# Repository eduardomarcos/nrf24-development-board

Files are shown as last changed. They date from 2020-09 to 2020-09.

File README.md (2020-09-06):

# NRF24 Development Board

The goal of this repository is to keep a version of a useful development boards for my [MySensors](https://www.mysensors.org/) projects based on atmega 328, esp32 and nrf24l01 module, so I do not need to wire all componentes into a breadboard.

## Atmega328 Development Board

Features:
* Almost all I/O pins available for direct connection
* Uses [3.3V Boost Buck](https://es.aliexpress.com/item/32822323191.html) for an input up to 5V (Considering that the sensor will be powered by a [TP4056](https://www.best-microcontroller-projects.com/tp4056.html) battery charger)
* If voltage regulator is wired by a connector headers instead of soldering, it would be possible to use a different voltage regulator (keep in mind that nrf24 module works with no more than ~3.6V or could be damaged)
* Internal voltage of 3.3 for the atmega 328
* NRF24L01 wired with a 10uF capacitor for noise reduction
* Reset button
* On board jumpers to disable 16 MHz crystal (and use internal 8 MHz from atmega 328)

This is the way it looks like:

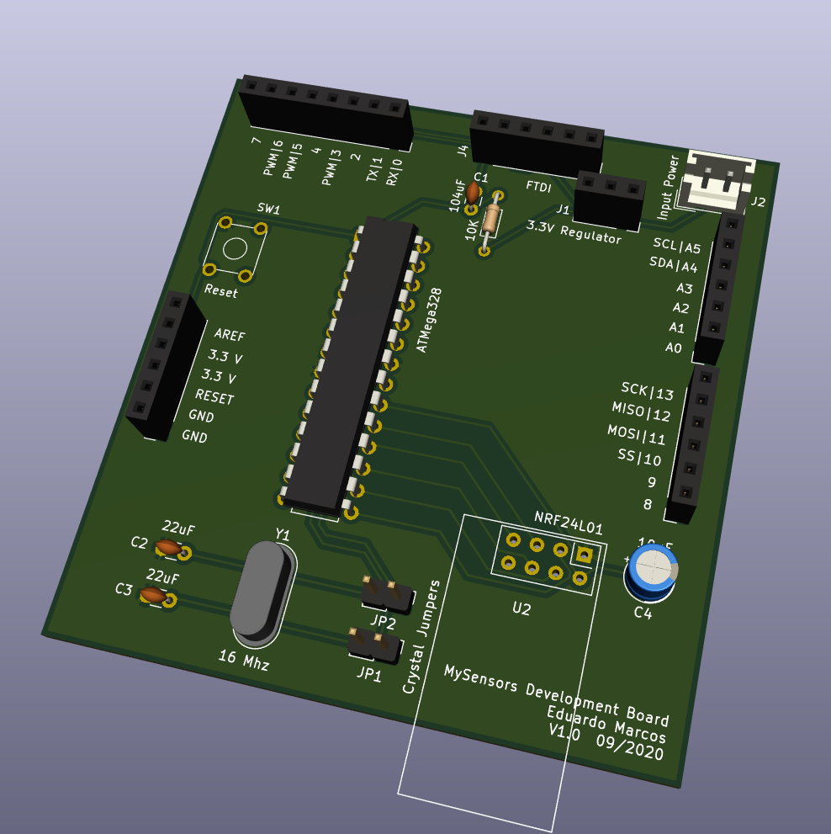
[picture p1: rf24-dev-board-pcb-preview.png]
Pcb board preview


## Esp32 Development Board

Features:
* All I/O pins available for direct connection
* NRF24L01 wired with an optional capacitor for noise reduction
* Err Tx and Rx led diodes for mysensors capability

This is the way it looks like:

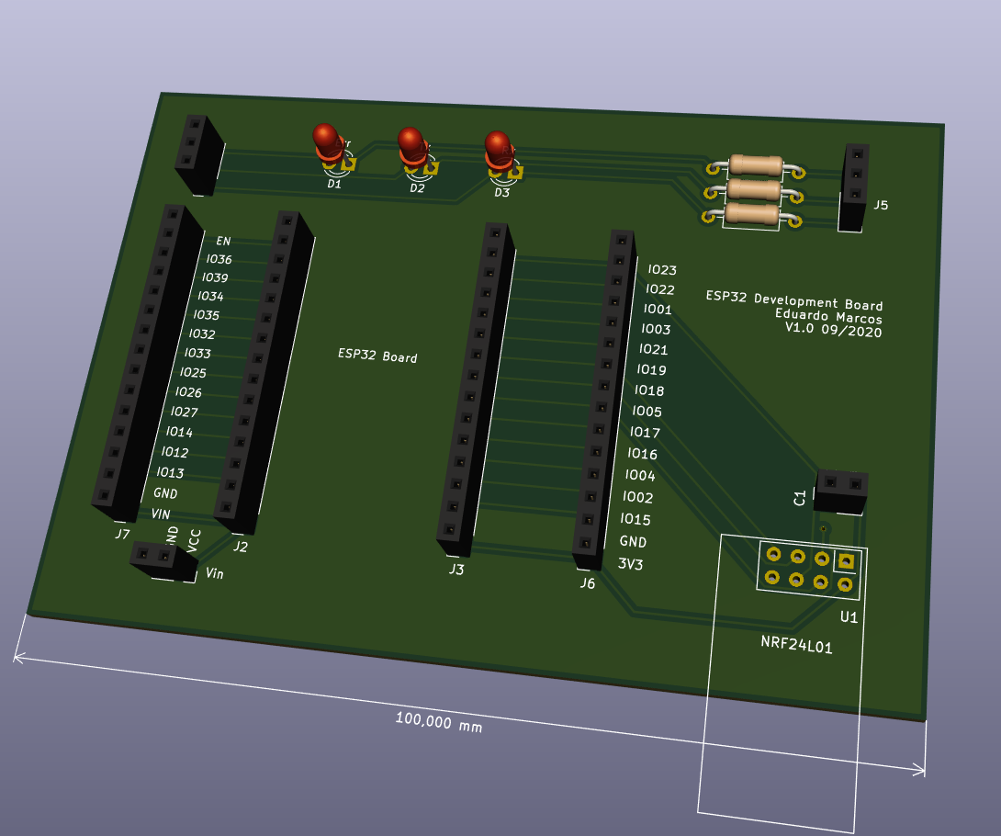
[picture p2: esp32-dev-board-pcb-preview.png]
Pcb board preview


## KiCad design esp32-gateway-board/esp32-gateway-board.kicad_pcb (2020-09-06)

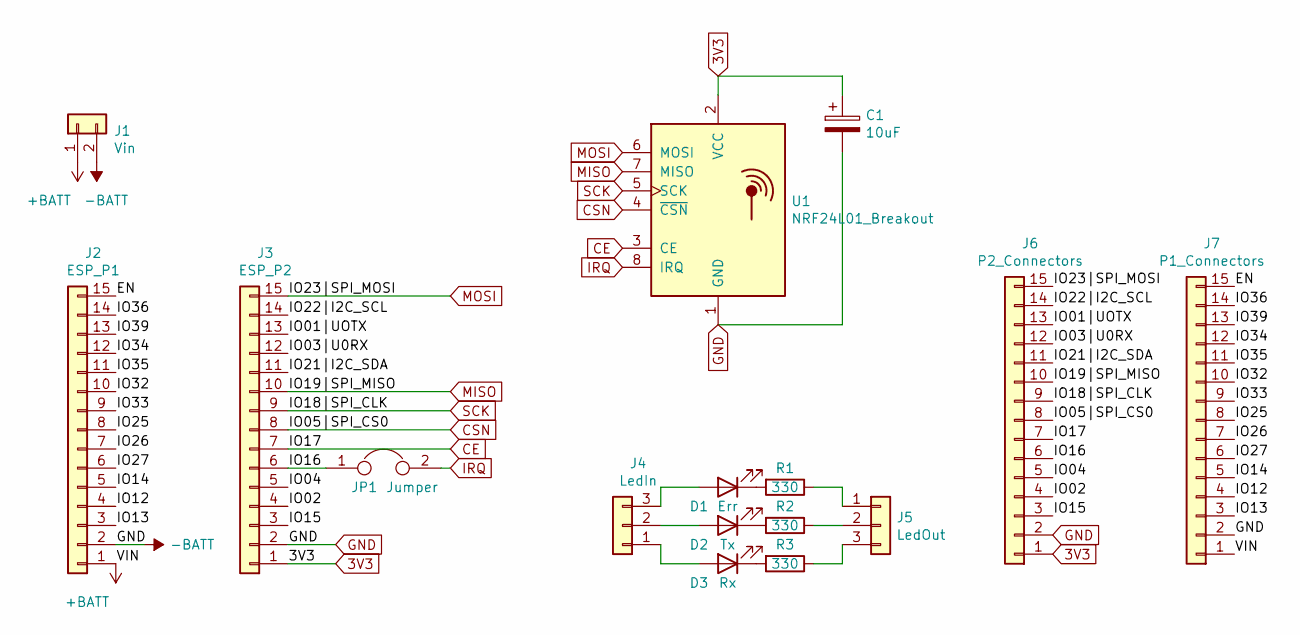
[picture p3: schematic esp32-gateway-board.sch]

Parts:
C1: 10uF; PinSocket_1x02_P2.54mm_Vertical
D1: Err; LED_D3.0mm
D2: Tx; LED_D3.0mm
D3: Rx; LED_D3.0mm
J1: Vin; PinSocket_1x02_P2.54mm_Vertical
J2: ESP_P1; PinSocket_1x15_P2.54mm_Vertical
J3: ESP_P2; PinSocket_1x15_P2.54mm_Vertical
J4: LedIn; PinSocket_1x03_P2.54mm_Vertical
J5: LedOut; PinSocket_1x03_P2.54mm_Vertical
J6: P2_Connectors; PinSocket_1x15_P2.54mm_Vertical
J7: P1_Connectors; PinSocket_1x15_P2.54mm_Vertical
JP1: Jumper; PinHeader_1x02_P2.54mm_Vertical
R1, R2, R3: 330; R_Axial_DIN0207_L6.3mm_D2.5mm_P10.16mm_Horizontal
U1: NRF24L01_Breakout; nRF24L01_Breakout

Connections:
3V3: C1.1, J3.1, J6.1, U1.2 (VCC)
+BATT: J1.1, J2.1, J7.1
/EN: J2.15, J7.15
/IO01|UOTX: J3.13, J6.13
/IO02: J3.4, J6.4
/IO03|U0RX: J3.12, J6.12
/IO04: J3.5, J6.5
/IO12: J2.4, J7.4
/IO13: J2.3, J7.3
/IO14: J2.5, J7.5
/IO15: J3.3, J6.3
/IO16: J3.6, J6.6, JP1.1
/IO21|I2C_SDA: J3.11, J6.11
/IO22|I2C_SCL: J3.14, J6.14
/IO25: J2.8, J7.8
/IO26: J2.7, J7.7
/IO27: J2.6, J7.6
/IO32: J2.10, J7.10
/IO33: J2.9, J7.9
/IO34: J2.12, J7.12
/IO35: J2.11, J7.11
/IO36: J2.14, J7.14
/IO39: J2.13, J7.13
CE: J3.7, J6.7, U1.3 (CE)
CSN: J3.8, J6.8, U1.4 (~CSN)
GND: C1.2, J1.2, J2.2, J3.2, J6.2, J7.2, U1.1 (GND)
MISO: J3.10, J6.10, U1.7 (MISO)
MOSI: J3.15, J6.15, U1.6 (MOSI)
unnamed: D1.1 (K), R1.2
unnamed: D1.2 (A), J4.3
unnamed: D2.1 (K), R2.2
unnamed: D2.2 (A), J4.2
unnamed: D3.1 (K), R3.2
unnamed: D3.2 (A), J4.1
unnamed: J5.1, R1.1
unnamed: J5.2, R2.1
unnamed: J5.3, R3.1
unnamed: JP1.2, U1.8 (IRQ)
SCK: J3.9, J6.9, U1.5 (SCK)

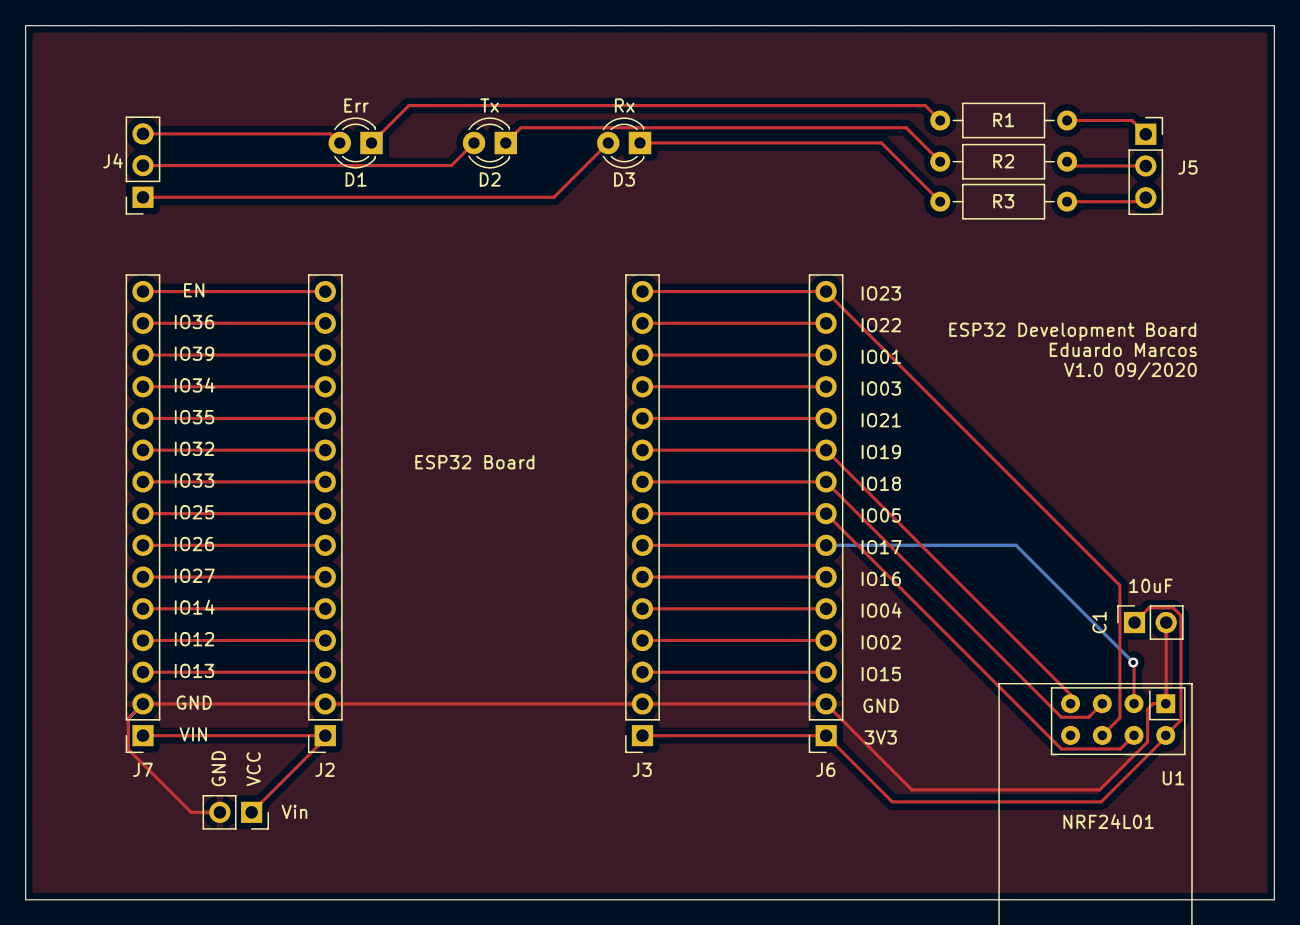
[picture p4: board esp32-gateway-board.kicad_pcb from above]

Board: 2 copper layers, 100.0 x 70.0 mm, 15 parts (0 on the bottom side), 38 nets.

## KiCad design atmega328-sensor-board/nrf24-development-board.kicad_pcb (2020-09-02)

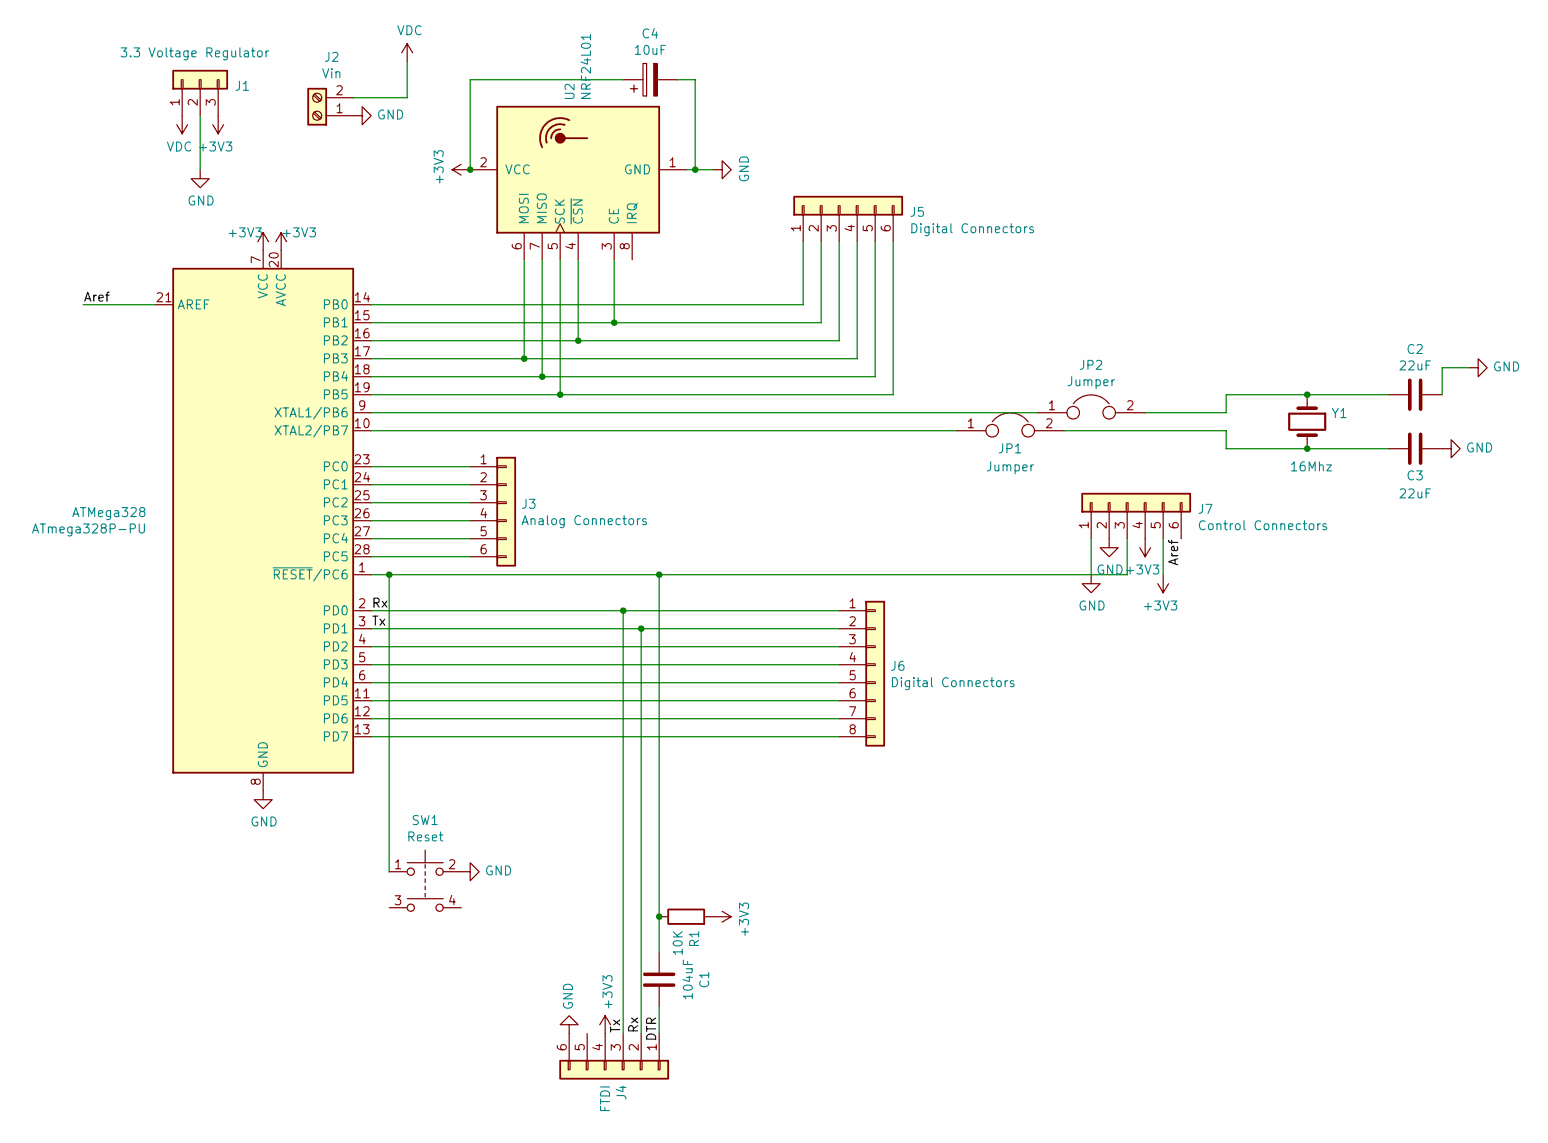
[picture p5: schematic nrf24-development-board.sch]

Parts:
ATMega328: ATmega328P-PU; DIP-28_W7.62mm
C1: 104uF; C_Disc_D3.0mm_W1.6mm_P2.50mm
C2, C3: 22uF; C_Disc_D3.0mm_W1.6mm_P2.50mm
C4: 10uF; CP_Radial_D5.0mm_P2.50mm
J1: 3.3 Voltage Regulator; PinSocket_1x03_P2.54mm_Vertical
J2: Vin; JST_EH_B2B-EH-A_1x02_P2.50mm_Vertical
J3: Analog Connectors; PinSocket_1x06_P2.54mm_Vertical
J4: FTDI; PinSocket_1x06_P2.54mm_Vertical
J5: Digital Connectors; PinSocket_1x06_P2.54mm_Vertical
J6: Digital Connectors; PinSocket_1x08_P2.54mm_Vertical
J7: Control Connectors; PinSocket_1x06_P2.54mm_Vertical
JP1, JP2: Jumper; PinHeader_1x02_P2.54mm_Vertical
R1: 10K; R_Axial_DIN0204_L3.6mm_D1.6mm_P7.62mm_Horizontal
SW1: Reset; SW_TH_Tactile_Omron_B3F-10xx
U2: NRF24L01; nRF24L01_Breakout
Y1: 16Mhz; Crystal_HC49-4H_Vertical

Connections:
+3V3: ATMega328.7 (VCC), ATMega328.20 (AVCC), C4.1, J1.3, J4.4, J7.4, J7.5, R1.2, U2.2 (VCC)
/Aref: ATMega328.21 (AREF), J7.6
/DTR: C1.1, J4.1
/Rx: ATMega328.2 (PD0), ATMega328.3 (PD1), J4.2, J4.3, J6.1, J6.2
unnamed: ATMega328.4 (PD2), J6.3
unnamed: ATMega328.5 (PD3), J6.4
unnamed: ATMega328.6 (PD4), J6.5
unnamed: ATMega328.9 (XTAL1/PB6), JP2.1
unnamed: ATMega328.10 (XTAL2/PB7), JP1.1
unnamed: ATMega328.11 (PD5), J6.6
unnamed: ATMega328.12 (PD6), J6.7
unnamed: ATMega328.13 (PD7), J6.8
unnamed: ATMega328.14 (PB0), J5.1
unnamed: ATMega328.15 (PB1), J5.2, U2.3 (CE)
unnamed: ATMega328.16 (PB2), J5.3, U2.4 (~CSN)
unnamed: ATMega328.17 (PB3), J5.4, U2.6 (MOSI)
unnamed: ATMega328.18 (PB4), J5.5, U2.7 (MISO)
unnamed: ATMega328.19 (PB5), J5.6, U2.5 (SCK)
unnamed: ATMega328.23 (PC0), J3.1
unnamed: ATMega328.24 (PC1), J3.2
unnamed: ATMega328.25 (PC2), J3.3
unnamed: ATMega328.26 (PC3), J3.4
unnamed: ATMega328.27 (PC4), J3.5
unnamed: ATMega328.28 (PC5), J3.6
unnamed: C2.2, JP2.2, Y1.1
unnamed: C3.2, JP1.2, Y1.2
VDC: J1.1, J2.2

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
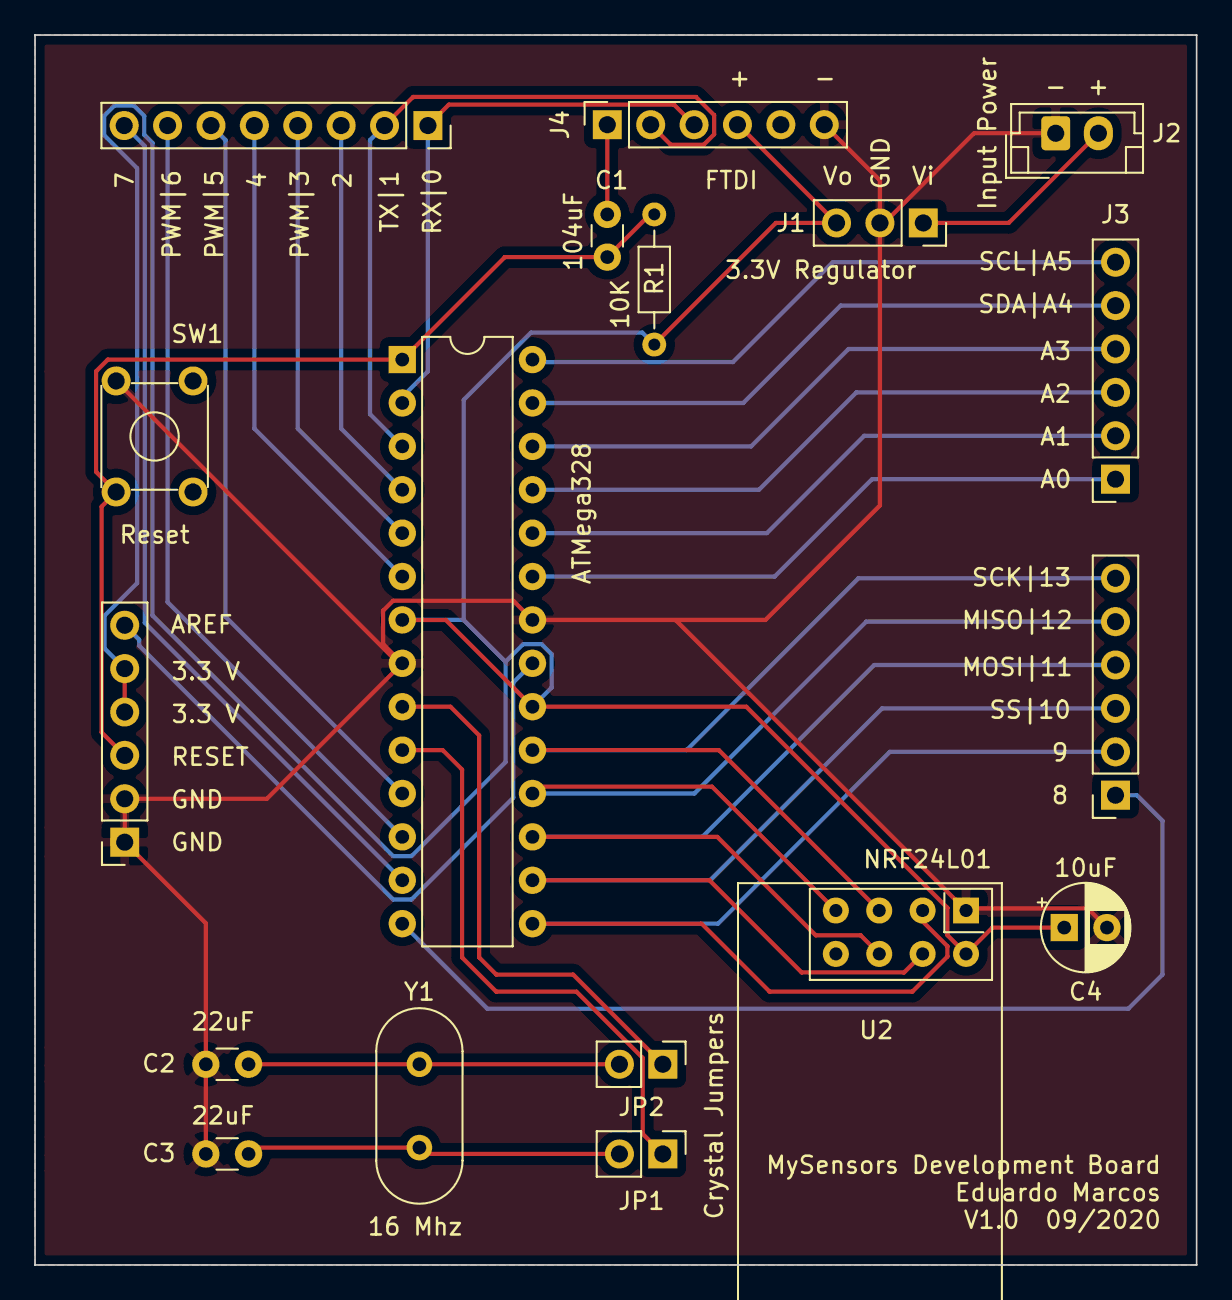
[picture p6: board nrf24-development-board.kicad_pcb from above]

Board: 2 copper layers, 68.0 x 72.0 mm, 18 parts (0 on the bottom side), 29 nets.

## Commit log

2020-09-01 Schematics for dev board
    [nrf24-development-board.kicad_pcb, nrf24-development-board.sch]
2020-09-01 footprint for schematics
    [nrf24-development-board.sch]
2020-09-02 pcb basic connections
    [nrf24-development-board.kicad_pcb, nrf24-development-board.sch]
2020-09-02 pcb tracks connected
    [nrf24-development-board.kicad_pcb]
2020-09-02 Pcb labeled
    [nrf24-development-board.kicad_pcb, nrf24-development-board.sch]
2020-09-02 upload preview picture of pcb
2020-09-02 update readme with pcb preview image
2020-09-02 moved board to atmega328 subfolder
    [nrf24-development-board.kicad_pcb, nrf24-development-board.sch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]
2020-09-02 esp32 pinout
    [esp32-gateway-board.kicad_pcb, esp32-gateway-board.sch]
2020-09-05 esp32 gateway with pcb
    [esp32-gateway-board.kicad_pcb, esp32-gateway-board.sch]
2020-09-06 upload esp32-board png
2020-09-06 update schematic
    [esp32-gateway-board.sch]
